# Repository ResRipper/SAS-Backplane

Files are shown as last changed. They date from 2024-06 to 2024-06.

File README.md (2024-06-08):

# SAS Backplane

> [!WARNING]
> Not final version, DO NOT USE

## Spec

- SFF-8087 -> 4x SAS 3.5 inch drive
- Power: 120 W

    | PWR Lane | Source   | Current per drive (A) | Total capacity (W) |
    | -------- | -------- | --------------------- | ------------------ |
    | 12V      | PSU      | 2                     | 96                 |
    | 5V       | 12V Lane | 1.2                   | 24                 |

## Change log

- v1.0 -> v1.1
    - SCH: v1.5
        - Use 2x `TPS82130` for 12V -> 5V conversion
            - Lower BOM count / cost
            - Smaller physical size
        - +12V power input connector
          - 4x M4 screws (2x +12, 2x GND) -> 1x ATX 4 pin connector
        - +12V filter group
          - 47uF cap -> 22uF ceramic cap
        - Add two 47uF caps to +12V input
        - Remove header for drive stat, remove `DNP` attribute for activity LEDs

    - PCB: v1.2
        - Change drive layout to vertical
        - Increase slot height from `27mm` to `28mm` for more airflow
        - Shrink board size to `100 x 90 mm`

## References

- https://pactech-inc.com/wp-content/uploads/2014/06/AMPH-8782-XXX-Send-out_01.jpg
- https://www.seagate.com/content/dam/seagate/assets/support/internal-hard-drive/enterprise-hard-drives/exos-x24/_shared/files/Seagate_Exos_24_SAS_ISE-SED-FIPs(12-16-2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
- https://www.seagate.com/content/dam/seagate/migrated-assets/www-content/product-content/enterprise-hdd-fam/exos-7e10/_shared/docs/100870879e.pdf
- https://www.seagate.com/content/dam/seagate/migrated-assets/www-content/manuals/exos-x-2x18/pdf/203859600a.pdf
- https://sata-io.org/system/files/specifications/SerialATA_Revision_3_1_Gold.pdf
- SFF-8609

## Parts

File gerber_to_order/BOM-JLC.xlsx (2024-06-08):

Designator | Comment | Footprint | Qty | LCSC | PN | Vendor
C1,C2,C11,C12,C20,C21 | 22u | Capacitor_SMD:C_0805_2012Metric | 6 | C602037 | CL21A226MAYNNNE | Samsung
C3,C10 | 47u | Capacitor_SMD:CP_Elec_6.3x5.8 | 2 | C2157870 | HHXE350ARA470MF61G | NCC
C4,C5,C13,C14,C27,C28 | 22u | Capacitor_SMD:C_0603_1608Metric | 6 | C159801 | CL10A226MQ8NRNE | Samsung
C6,C7,C15,C16,C29,C30 | 100n | Capacitor_SMD:C_0402_1005Metric | 6 | C60474 | CC0402KRX7R7BB104 | YAGEO
C8,C9,C17,C18,C23,C24 | 100n | Capacitor_SMD:C_0402_1005Metric | 6 | C105883 | CC0402KRX7R8BB104 | YAGEO
C19,C22 | 1u | Capacitor_SMD:C_0402_1005Metric | 2 | C52923 | CL05A105KA5NQNC | Samsung
C25,C26 | 100n | Capacitor_SMD:C_1206_3216Metric | 2 | C23631 | CC1206KKX7RDBB102 | YAGEO
D1,D2,D3,D4 | LED | LED_SMD:LED_0603_1608Metric | 4 | C7496818 | P2-0603G1TS2-06T-002 | TUOZHAN
J1 | TE_1888019-6 | Library:TE_1888019-6 | 1 | C2979967 | LD2136V-MCUL6 | FOXCONN
J2,J3,J4,J5 | Amphenol_10144871-002-LF | Library:Amphenol_10144871-002-TRLF | 4 | C2906136 | 91904-291512 | Umaxconn
J6 | PWR_IN | Library:XKB_X9357WR-2x02-N2SN | 1 | C388758 | X9357WR-2x02-N2SN | XKB Connecitity
Q1,Q2,Q3,Q4 | PMBT3904,215 | Package_TO_SOT_SMD:SOT-23 | 4 | C8667 | PMBT3904,215 | Nexperia
R1,R2,R5,R6 | 110 | Resistor_SMD:R_0402_1005Metric | 4 | C295884 | RC0402JR-07110RL | YAGEO
R3,R4,R7,R8 | 20k | Resistor_SMD:R_0402_1005Metric | 4 | C137902 | RC0402JR-0720KL | YAGEO
R9,R10 | 1M | Resistor_SMD:R_0603_1608Metric | 2 | C144621 | AC0603JR-071ML | YAGEO
R11,R13 | 523k | Resistor_SMD:R_0402_1005Metric | 2 | C227128 | AC0402FR-07523KL | YAGEO
R12,R14 | 100k | Resistor_SMD:R_0402_1005Metric | 2 | C60491 | RC0402FR-07100KL | YAGEO
U1 | TI_TLV743P | Library:Ti_DBV0005A | 1 | C408972 | TLV74333PDBVR | Texas Instruments
U2,U3 | TPS82130 | Package_LGA:Texas_SIL0008D_MicroSiP-8-1EP_2.8x3mm_P0.65mm_EP1.1x1.9mm_ThermalVias | 2 | C473914 | TPS82130SILR | Texas Instruments

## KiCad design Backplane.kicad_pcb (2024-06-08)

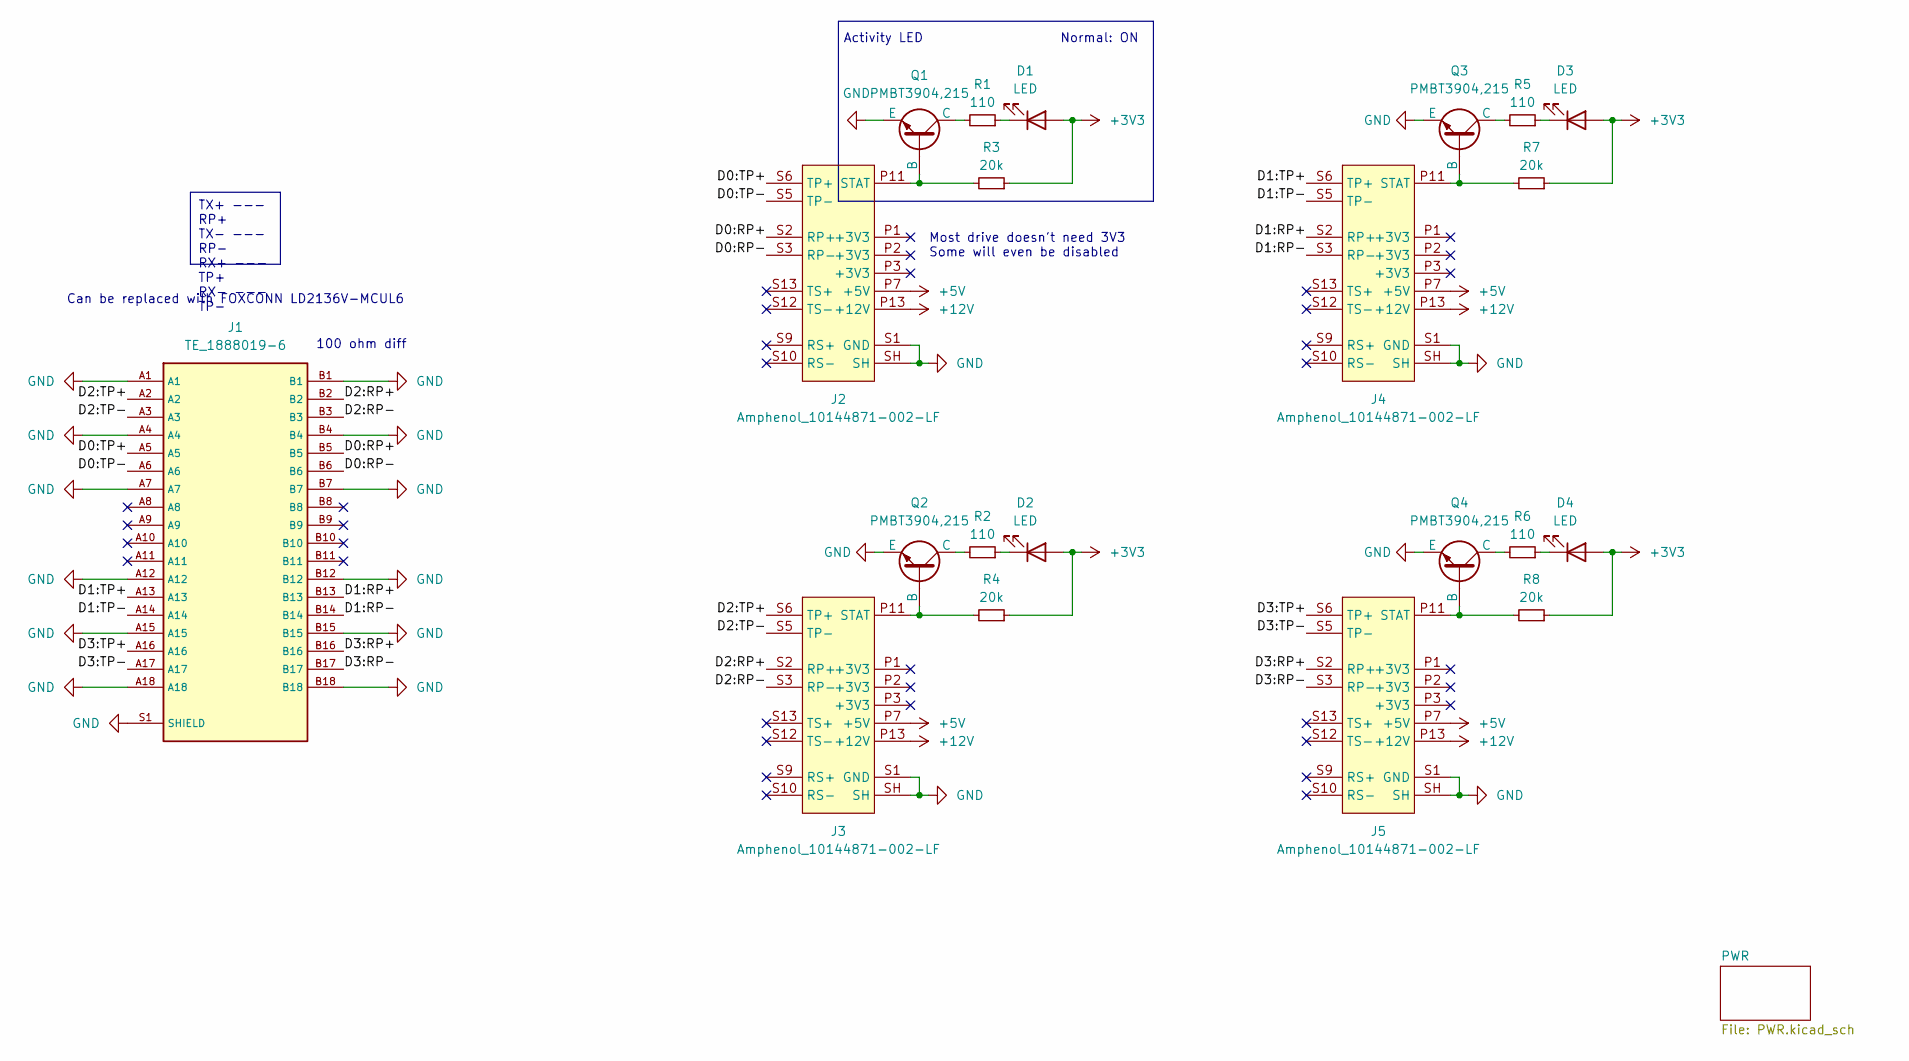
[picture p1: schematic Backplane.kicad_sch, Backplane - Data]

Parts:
D1, D2, D3, D4: LED; LED_0603_1608Metric; LCSC C7496818
J1: TE_1888019-6
J2, J3, J4, J5: Amphenol_10144871-002-LF; Amphenol_10144871-002-TRLF
Q1, Q2, Q3, Q4: PMBT3904,215; SOT-23; LCSC C8667
R1, R2, R5, R6: 110; R_0402_1005Metric; LCSC C295884
R3, R4, R7, R8: 20k; R_0402_1005Metric; LCSC C137902

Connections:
+3V3: D1.2 (A), D2.2 (A), D3.2 (A), D4.2 (A), R3.1, R4.1, R7.1, R8.1; also elsewhere on the board
+5V: J2.P7 (+5V), J2.P8 (+5V), J2.P9 (+5V), J3.P7 (+5V), J3.P8 (+5V), J3.P9 (+5V), J4.P7 (+5V), J4.P8 (+5V), J4.P9 (+5V), J5.P7 (+5V), J5.P8 (+5V), J5.P9 (+5V); also elsewhere on the board
+12V: J2.P13 (+12V), J2.P14 (+12V), J2.P15 (+12V), J3.P13 (+12V), J3.P14 (+12V), J3.P15 (+12V), J4.P13 (+12V), J4.P14 (+12V), J4.P15 (+12V), J5.P13 (+12V), J5.P14 (+12V), J5.P15 (+12V); also elsewhere on the board
/D0:RP+: J1.B5, J2.S2 (RP+)
/D0:RP-: J1.B6, J2.S3 (RP-)
/D0:TP+: J1.A5, J2.S6 (TP+)
/D0:TP-: J1.A6, J2.S5 (TP-)
/D1:RP+: J1.B13, J4.S2 (RP+)
/D1:RP-: J1.B14, J4.S3 (RP-)
/D1:TP+: J1.A13, J4.S6 (TP+)
/D1:TP-: J1.A14, J4.S5 (TP-)
/D2:RP+: J1.B2, J3.S2 (RP+)
/D2:RP-: J1.B3, J3.S3 (RP-)
/D2:TP+: J1.A2, J3.S6 (TP+)
/D2:TP-: J1.A3, J3.S5 (TP-)
/D3:RP+: J1.B16, J5.S2 (RP+)
/D3:RP-: J1.B17, J5.S3 (RP-)
/D3:TP+: J1.A16, J5.S6 (TP+)
/D3:TP-: J1.A17, J5.S5 (TP-)
GND: J1.A1, J1.A4, J1.A7, J1.A12, J1.A15, J1.A18, J1.B1, J1.B4, J1.B7, J1.B12, J1.B15, J1.B18, J1.S1 (SHIELD), J1.S2 (SHIELD), J1.S3 (SHIELD), J1.S4 (SHIELD), J1.S5 (SHIELD), J1.S6 (SHIELD), J2.P4 (GND), J2.P5 (GND), J2.P6 (GND), J2.P10 (GND), J2.P12 (GND), J2.S1 (GND), J2.S4 (GND), J2.S7 (GND), J2.S8 (GND), J2.S11 (GND), J2.S14 (GND), J2.SH, J3.P4 (GND), J3.P5 (GND), J3.P6 (GND), J3.P10 (GND), J3.P12 (GND), J3.S1 (GND), J3.S4 (GND), J3.S7 (GND), J3.S8 (GND), J3.S11 (GND), J3.S14 (GND), J3.SH, J4.P4 (GND), J4.P5 (GND), J4.P6 (GND), J4.P10 (GND), J4.P12 (GND), J4.S1 (GND), J4.S4 (GND), J4.S7 (GND), J4.S8 (GND), J4.S11 (GND), J4.S14 (GND), J4.SH, J5.P4 (GND), J5.P5 (GND), J5.P6 (GND), J5.P10 (GND), J5.P12 (GND), J5.S1 (GND), J5.S4 (GND), J5.S7 (GND), J5.S8 (GND), J5.S11 (GND), J5.S14 (GND), J5.SH, Q1.3 (E), Q2.3 (E), Q3.3 (E), Q4.3 (E); also elsewhere on the board
unnamed: D1.1 (K), R1.1
unnamed: D2.1 (K), R2.1
unnamed: D3.1 (K), R5.1
unnamed: D4.1 (K), R6.1
unnamed: J2.P11 (STAT), Q1.2 (B), R3.2
unnamed: J3.P11 (STAT), Q2.2 (B), R4.2
unnamed: J4.P11 (STAT), Q3.2 (B), R7.2
unnamed: J5.P11 (STAT), Q4.2 (B), R8.2
unnamed: Q1.1 (C), R1.2
unnamed: Q2.1 (C), R2.2
unnamed: Q3.1 (C), R5.2
unnamed: Q4.1 (C), R6.2

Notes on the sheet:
TX+ --- RP+ TX- --- RP- RX+ --- TP+ RX- --- TP-
100 ohm diff
Most drive doesn't need 3V3 Some will even be disabled
Normal: ON
Can be replaced with FOXCONN LD2136V-MCUL6
Activity LED

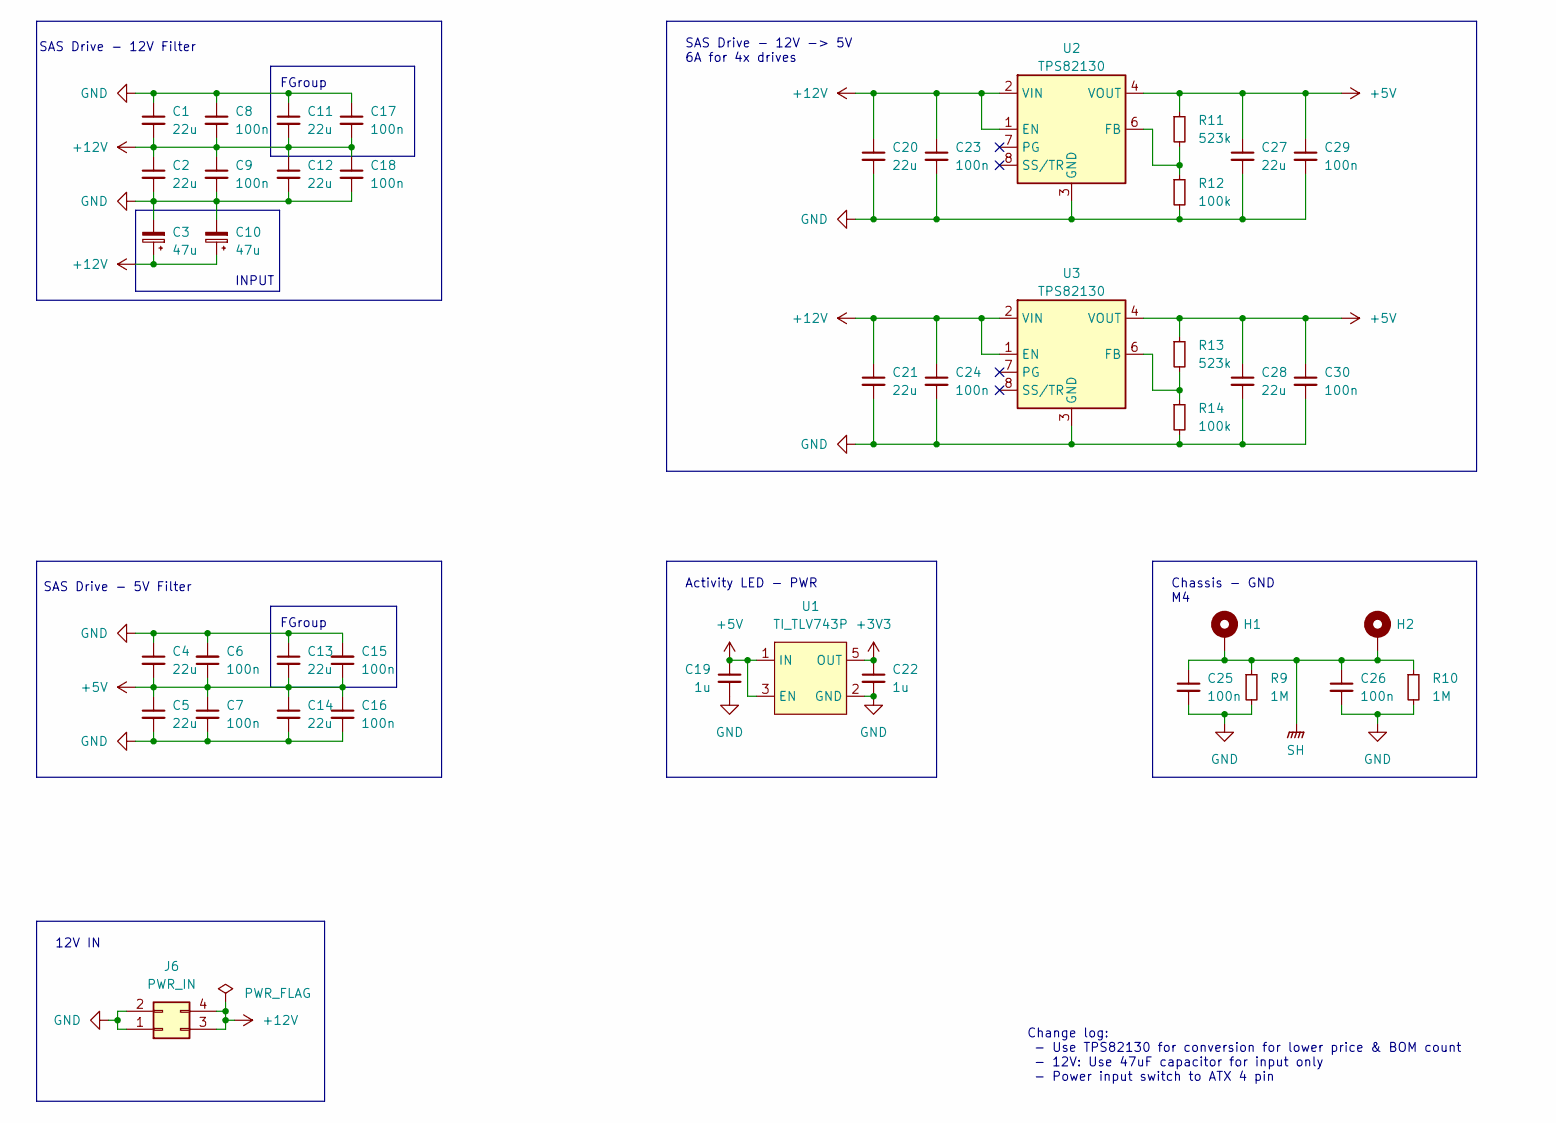
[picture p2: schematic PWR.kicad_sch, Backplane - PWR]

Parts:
C1, C2, C11, C12, C20, C21: 22u; C_0805_2012Metric; LCSC C602037
C3, C10: 47u; CP_Elec_6.3x5.8; LCSC C2157870
C4, C5, C13, C14, C27, C28: 22u; C_0603_1608Metric; LCSC C159801
C6, C7, C15, C16, C29, C30: 100n; C_0402_1005Metric; LCSC C60474
C8, C9, C17, C18, C23, C24: 100n; C_0402_1005Metric; LCSC C105883
C19, C22: 1u; C_0402_1005Metric; LCSC C52923
C25, C26: 100n; C_1206_3216Metric; LCSC C23631
H1, H2: MountingHole_4.3mm_M4_Pad_TopBottom
J6: PWR_IN; XKB_X9357WR-2x02-N2SN; LCSC C388758
R9, R10: 1M; R_0603_1608Metric; LCSC C144621
R11, R13: 523k; R_0402_1005Metric; LCSC C227128
R12, R14: 100k; R_0402_1005Metric; LCSC C60491
U1: TI_TLV743P; Ti_DBV0005A; LCSC C408972
U2, U3: TPS82130; Texas_SIL0008D_MicroSiP-8-1EP_2.8x3mm_P0.65mm_EP1.1x1.9mm_T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; LCSC C473914

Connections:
+3V3: C22.1, U1.5 (OUT); also elsewhere on the board
+5V: C4.2, C5.1, C6.1, C7.1, C13.2, C14.1, C15.1, C16.1, C19.1, C27.1, C28.1, C29.1, C30.1, R11.1, R13.1, U1.1 (IN), U1.3 (EN), U2.4 (VOUT), U2.5 (VOUT), U3.4 (VOUT), U3.5 (VOUT); also elsewhere on the board
+12V: C1.2, C2.1, C3.1, C8.2, C9.1, C10.1, C11.2, C12.1, C17.2, C18.1, C20.1, C21.1, C23.1, C24.1, J6.3, J6.4, U2.1 (EN), U2.2 (VIN), U3.1 (EN), U3.2 (VIN); also elsewhere on the board
GND: C1.1, C2.2, C3.2, C4.1, C5.2, C6.2, C7.2, C8.1, C9.2, C10.2, C11.1, C12.2, C13.1, C14.2, C15.2, C16.2, C17.1, C18.2, C19.2, C20.2, C21.2, C22.2, C23.2, C24.2, C25.2, C26.2, C27.2, C28.2, C29.2, C30.2, J6.1, J6.2, R9.2, R10.2, R12.2, R14.2, U1.2 (GND), U2.3 (GND), U2.9 (GND), U3.3 (GND), U3.9 (GND); also elsewhere on the board
unnamed: R11.2, R12.1, U2.6 (FB)
unnamed: R13.2, R14.1, U3.6 (FB)
SH: C25.1, C26.1, H1.1, H2.1, R9.1, R10.1

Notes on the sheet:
Change log: - Use TPS82130 for conversion for lower price & BOM count - 12V: Use 47uF capacitor for input only - Power input switch to ATX 4 pin
SAS Drive - 12V -> 5V 6A for 4x drives
12V IN
Chassis - GND M4
INPUT
FGroup
Activity LED - PWR
SAS Drive - 12V Filter
SAS Drive - 5V Filter

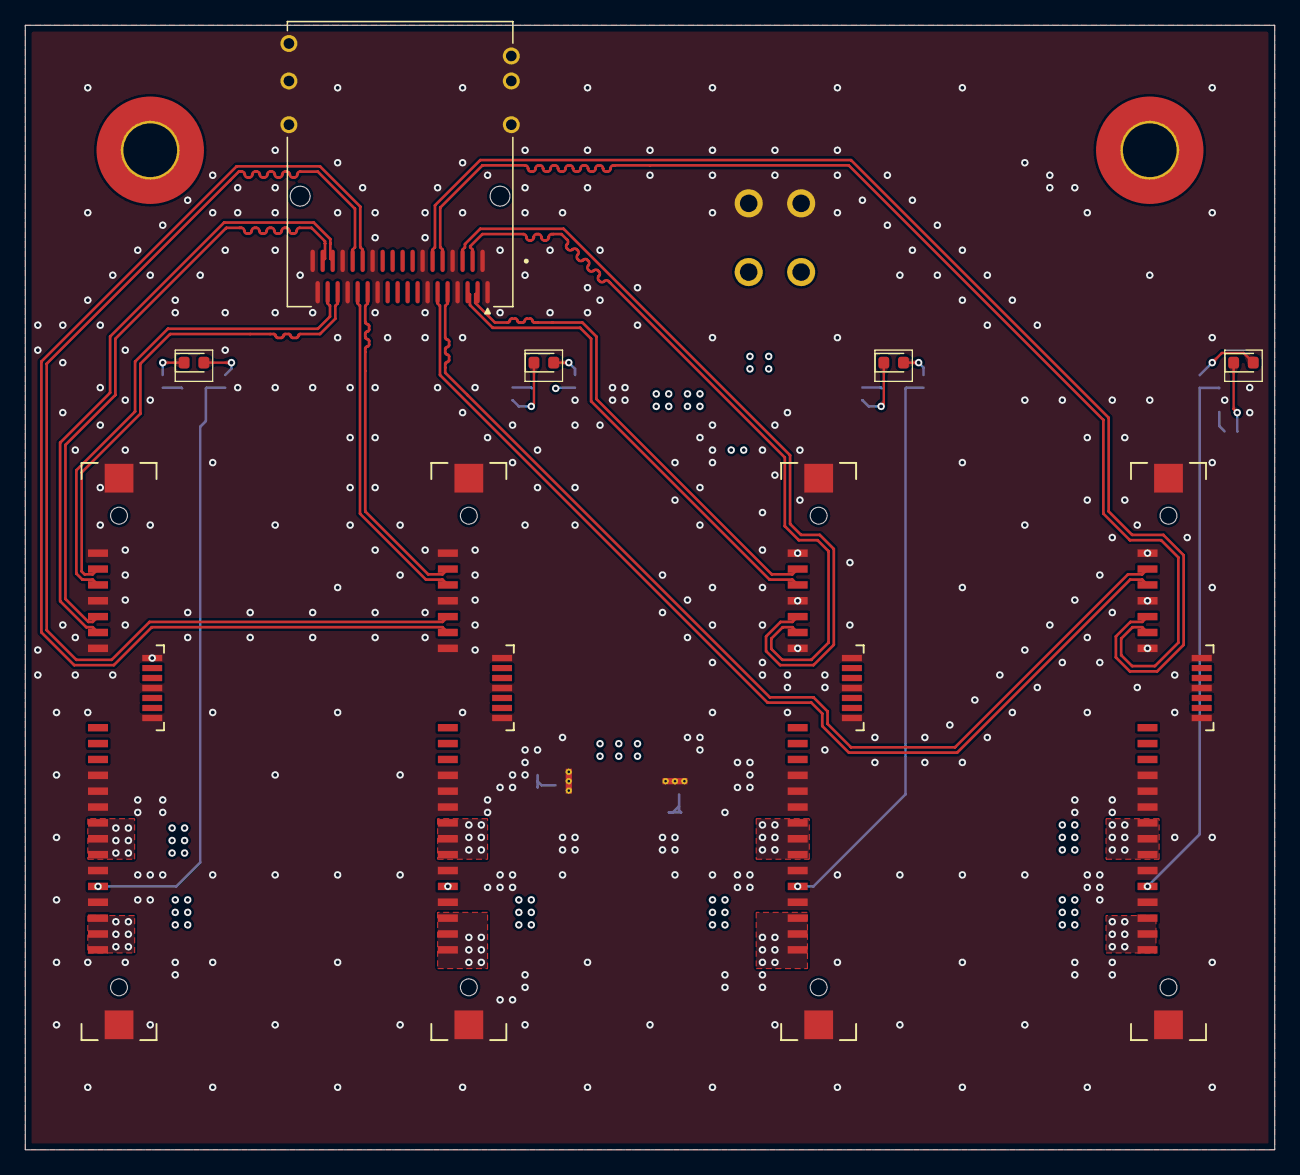
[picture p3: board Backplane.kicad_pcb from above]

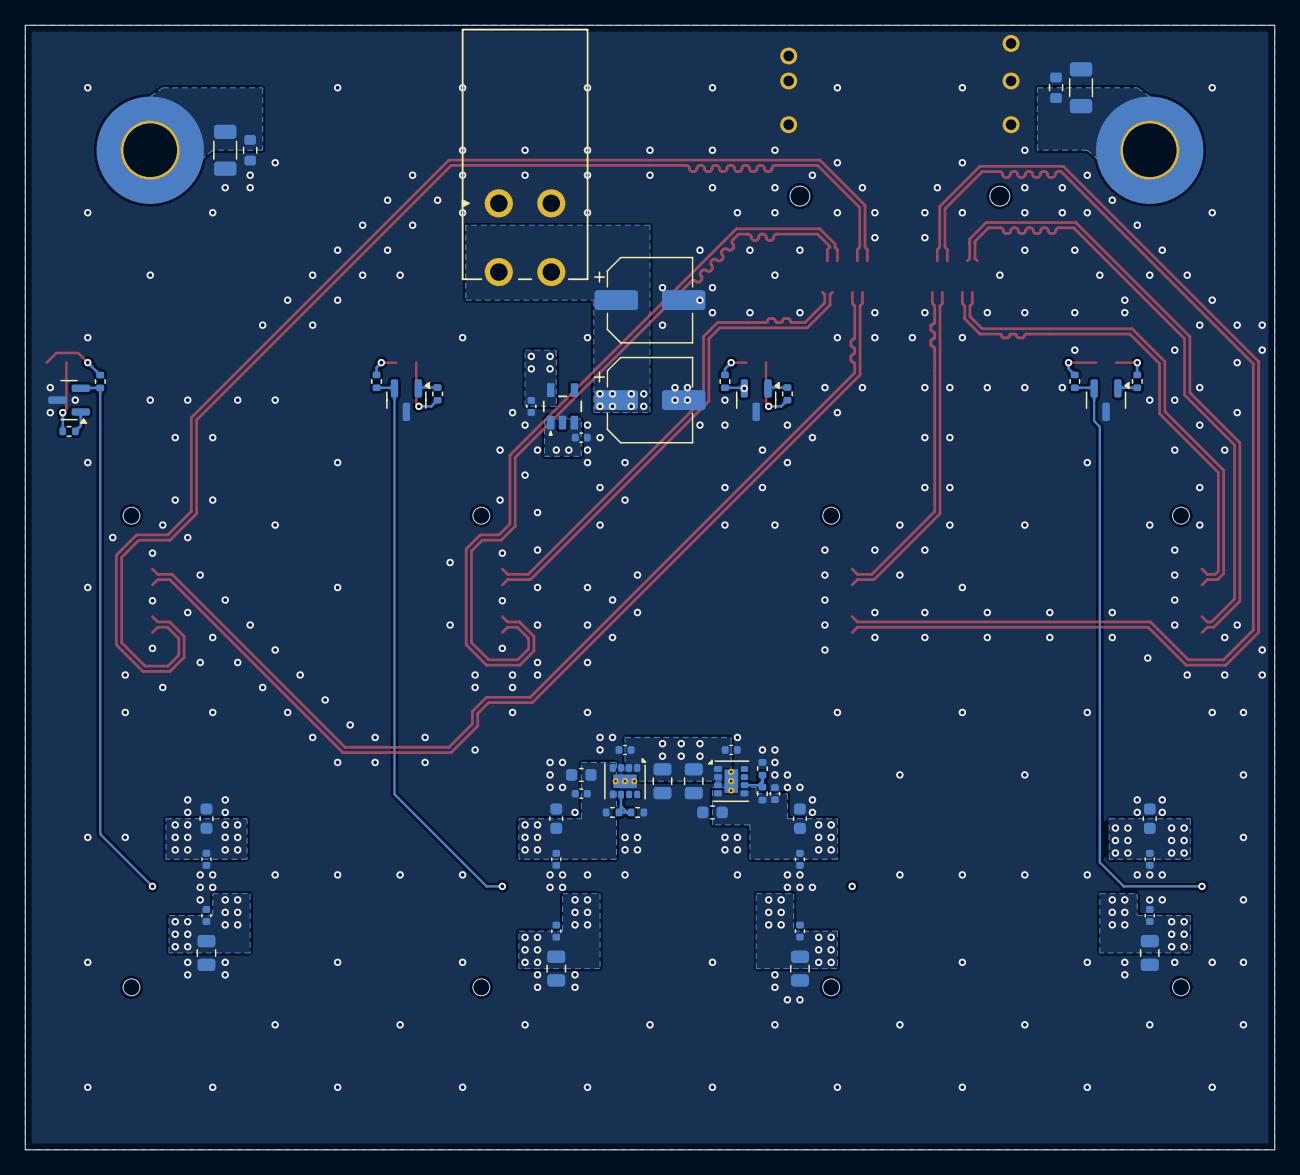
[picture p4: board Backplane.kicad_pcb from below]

Board: 4 copper layers, 100.0 x 90.0 mm, 63 parts (52 on the bottom side), 35 nets.

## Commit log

2024-05-27 Version 1.0
    [PWR.kicad_sch, SAS_Backplane.kicad_pcb, SAS_Backplane.kicad_sch]
2024-06-08 Version 1.1
    [BOM-JLC.xlsx, Backplane.kicad_pcb, Backplane.kicad_sch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]
